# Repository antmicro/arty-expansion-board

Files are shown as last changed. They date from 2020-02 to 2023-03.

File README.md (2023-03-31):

# Antmicro Arty A7 expansion board

Copyright (c) 2019-2023 [Antmicro](https://www.antmicro.com)



Arty A7 Expansion Board

## Overview

This project contains open hardware design files for expansion board compatible with Digilent [Arty A7 development platform](https://store.digilentinc.com/arty-a7-artix-7-fpga-development-board-for-makers-and-hobbyists/).
The expansion board utilizes a set of PMOD connectors on Arty board to provide additional IO interfaces.

## Project structure

The main directory contains the KiCAD design files, LICENSE and README.
The remaining files are stored in the following directories:

* ``3d-model`` -  contains mechanical model of the board
* ``lib`` - contains the component libraries
* ``doc`` - contains selected files for device fabrication (schematic in PDF, BoM)
* ``img`` - contains graphics for this README

## Key features

* HDMI connector
* microSD card connector
* USB 2.0 host controller implemented with Maxim [MAX3421EEHJ](https://datasheets.maximintegrated.com/en/ds/MAX3421E.pdf)
* Analog audio output implemented with Cirrus Logic [CS4344](https://www.cirrus.com/products/cs4344-45-48) D/A converter
* Analog (line) audio input implemented with Cirrus Logic [CS5343](https://www.cirrus.com/products/cs5343-44) A/D converter
* GPIO expander with LED indicators

## License

This project is licensed under the [Apache-2.0 ](LICENSE) license.

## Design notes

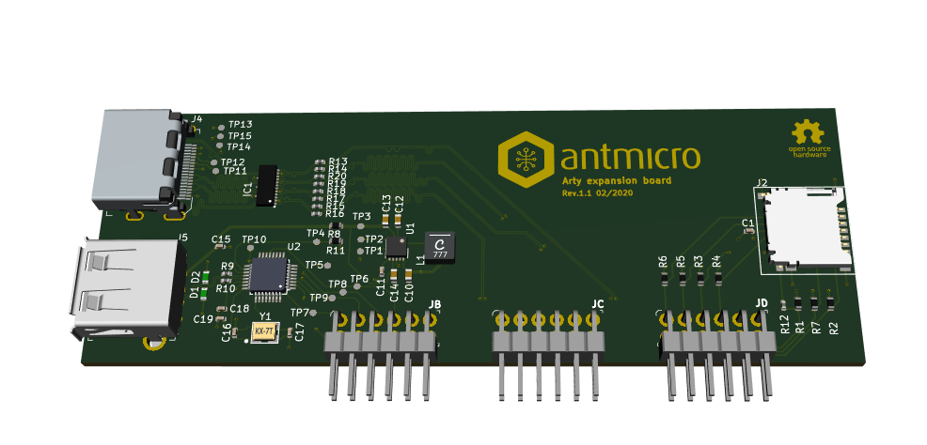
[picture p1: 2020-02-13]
img/expansion-board.png

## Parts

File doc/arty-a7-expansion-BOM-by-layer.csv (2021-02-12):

Reference | Quantity | Value | Footprint | Manufacturer | MPN | Layer
C1 C15 C18 C19 C31 | 5 | C_100n_0402_6V3 | 0402-cap | Walsin | 0402X104K6R3CT | Top
C10 C12 C13 C14 | 4 | C_22u_0603 | 0603-cap | MURATA | GRM188R60J226MEA0D | Top
C11 | 1 | C_10n_0402 | 0402-cap | AVX | 04025G103ZAT2A | Top
C16 C17 | 2 | C_22p_0402 | 0402-cap | YAGEO | CC0402JRNPO9BN220 | Top
C2 C3 C6 C7 C8 C21 C22 | 7 | C_100n_0402_16V | 0402-cap | MULTICOMP | MC0402B104K160CT | Top
C24 C27 C28 | 3 | C_1u_0402 | 0402-cap | TDK | C1005X6S1A105K050BC | Top
C25 C26 | 2 | C_3u3_0603 | 0603-cap | KEMET | C0603C335M9PACTU | Top
C29 C30 | 2 | C_2n7_0603 | 0603-cap | KEMET | C0603C272K5RACTU | Top
C32 C33 | 2 | C_180p_0402 | 0402-cap | AVX | 04025A181JAT2A | Top
C4 C5 | 2 | C_4u7_0402 | 0402-cap | MURATA | GRM155R61A475MEAAD | Top
C9 C20 C23 | 3 | C_10u_0402 | 0402-cap | MURATA | GRM155R60J106ME44D | Top
D1 D2 | 2 | PGB1010603MR | PGB1010603MR | Littelfuse Inc. | PGB1010603MR | Top
D3 D4 D5 D6 D7 D8 | 6 | LG_L29K-G2J1-24-Z | LED_0603 | OSRAM Opto Semiconductors Inc. | LG L29K-G2J1-24-Z | Top
FB1 FB2 | 2 | BLM15AG601SN1D | 0402-res | Murata | BLM15AG601SN1D | Top
IC1 | 1 | TPD8S009DSMR | R-PDSO-N15 | Texas Instruments | TPD8S009DSMR | Top
IC2 | 1 | PCA9500PW | TSSOP-16 | NXP | PCA9500PW | Top
J1 | 1 | SJ-43516-SMT-GR | CUI_SJ-43516-SMT-GR | CUI Inc | SJ-43516-SMT-GR | Top
J2 | 1 | DM3AT-SF-PEJM5 | MicroSD_DM3AT-SF-PEJM5 | HIROSE | DM3AT-SF-PEJM5 | Top
J3 | 1 | SJ-43516-SMT-BE | CUI_SJ-43516-SMT-BE | CUI Inc | SJ-43516-SMT-BE | Top
J4 | 1 | 685119134923 | HDMI_A_Female_685119134923 | Amphenol | 685119134923 | Top
J5 | 1 | UE27AC54100 | USB_A_Female_UE27AC54100 | Amphenol ICC (Commercial Products) | UE27AC54100 | Top
JA1 JB1 JC1 JD1 | 4 | 10883121 | PinHeader_6x2_P2.54mm_Horizontal_Mirrored | Molex | 10883121 | Top
L1 | 1 | XFL4020-102MEC | XFL4020-102MEB | Coilcraft | XFL4020-102MEC | Top
Q1 | 1 | BSS138APW | SC70-3 | ON Semiconductor | BSS138PW | Top
R1 R2 R3 R4 R5 R6 R7 | 7 | R_20k_0402 | 0402-res | VISHAY | CRCW040220K0FKED | Top
R11 R24 R28 R30 | 4 | R_10k_0402 | 0402-res | VISHAY | CRCW040210K0FKEDHP | Top
R12 | 1 | R_220R_0402 | 0402-res | Panasonic | ERJ2GEJ221X | Top
R22 R23 | 2 | R_1R_0402 | 0402-res | YAGEO | RC0402FR-071RL | Top
R29 R31 R34 R35 | 4 | R_5k1_0603 | 0603-res | Vishay | CRCW06035K10FKEA | Top
R32 R33 | 2 | R_470R_0402 | 0402-res | VISHAY | CRCW0402470RFKED | Top
R36 R37 | 2 | R_2k_0402 | 0402-res | VISHAY | CRCW04022K00FKED | Top
R38 | 1 | R_100k_0402 | 0402-res | VISHAY | CRCW0402100KFKEDHP | Top
R40 R41 R42 R43 | 4 | R_100R_0402 | 0402-res | BOURNS | CR0402-FX-1000GLF | Top
R44 R46 | 2 | R_330R_0402 | 0402-res | MULTICOMP | MCMR04X3300FTL | Top
R45 | 1 | R_10k_0402 | 0402-res | VISHAY | CRCW040210K0FKEDHP | Top
R8 R13 R14 R15 R16 R17 R18 R19 R20 R21 R25 R26 R27 R39 | 14 | R_0R_0402 | 0402-res | PANASONIC | ERJ2GE0R00X | Top
R9 R10 | 2 | R_22R_0402 | 0402-res | VISHAY | CRCW040222R0FKED | Top
U1 | 1 | TPS61232DRCT | VSON-10-1EP_3x3mm | Texas Instruments | TPS61232DRCT | Top
U2 | 1 | MAX3421EEHJ | TQFP-32_5x5mm | Maxim integrated | MAX3421EEHJ | Top
U3 | 1 | CS4344-CZZ | 10TSSOP | Cirrus Logic | CS4344-CZZ | Top
U4 | 1 | CS5343-CZZ | 10TSSOP | Cirrus Logic | CS5343-CZZ | Top
U5 | 1 | NC7SZ126P5X | SC-70-5 | ON Semiconductor | NC7SZ126P5X | Top
Y1 | 1 | ABM8G-12.000MHZ-18-D2Y-T | KX-7 | Abracon | ABM8G-12.000MHZ-18-D2Y-T | Top
N1 | 1 | antmicro_logo | antmicro-logo_scaled_30mm |  |  | Virtual
N2 | 1 | oshw_logo | oshw-logo |  |  | Virtual
TP1 TP2 TP3 TP5 TP6 TP7 TP8 TP9 TP10 TP11 TP12 TP13 TP14 TP15 | 14 | TP_SMD1MM | Testpoint_smd_1mm |  |  | Virtual
TP4 | 1 | TP_SMD1MM- | Testpoint_smd_1mm |  |  | Virtual

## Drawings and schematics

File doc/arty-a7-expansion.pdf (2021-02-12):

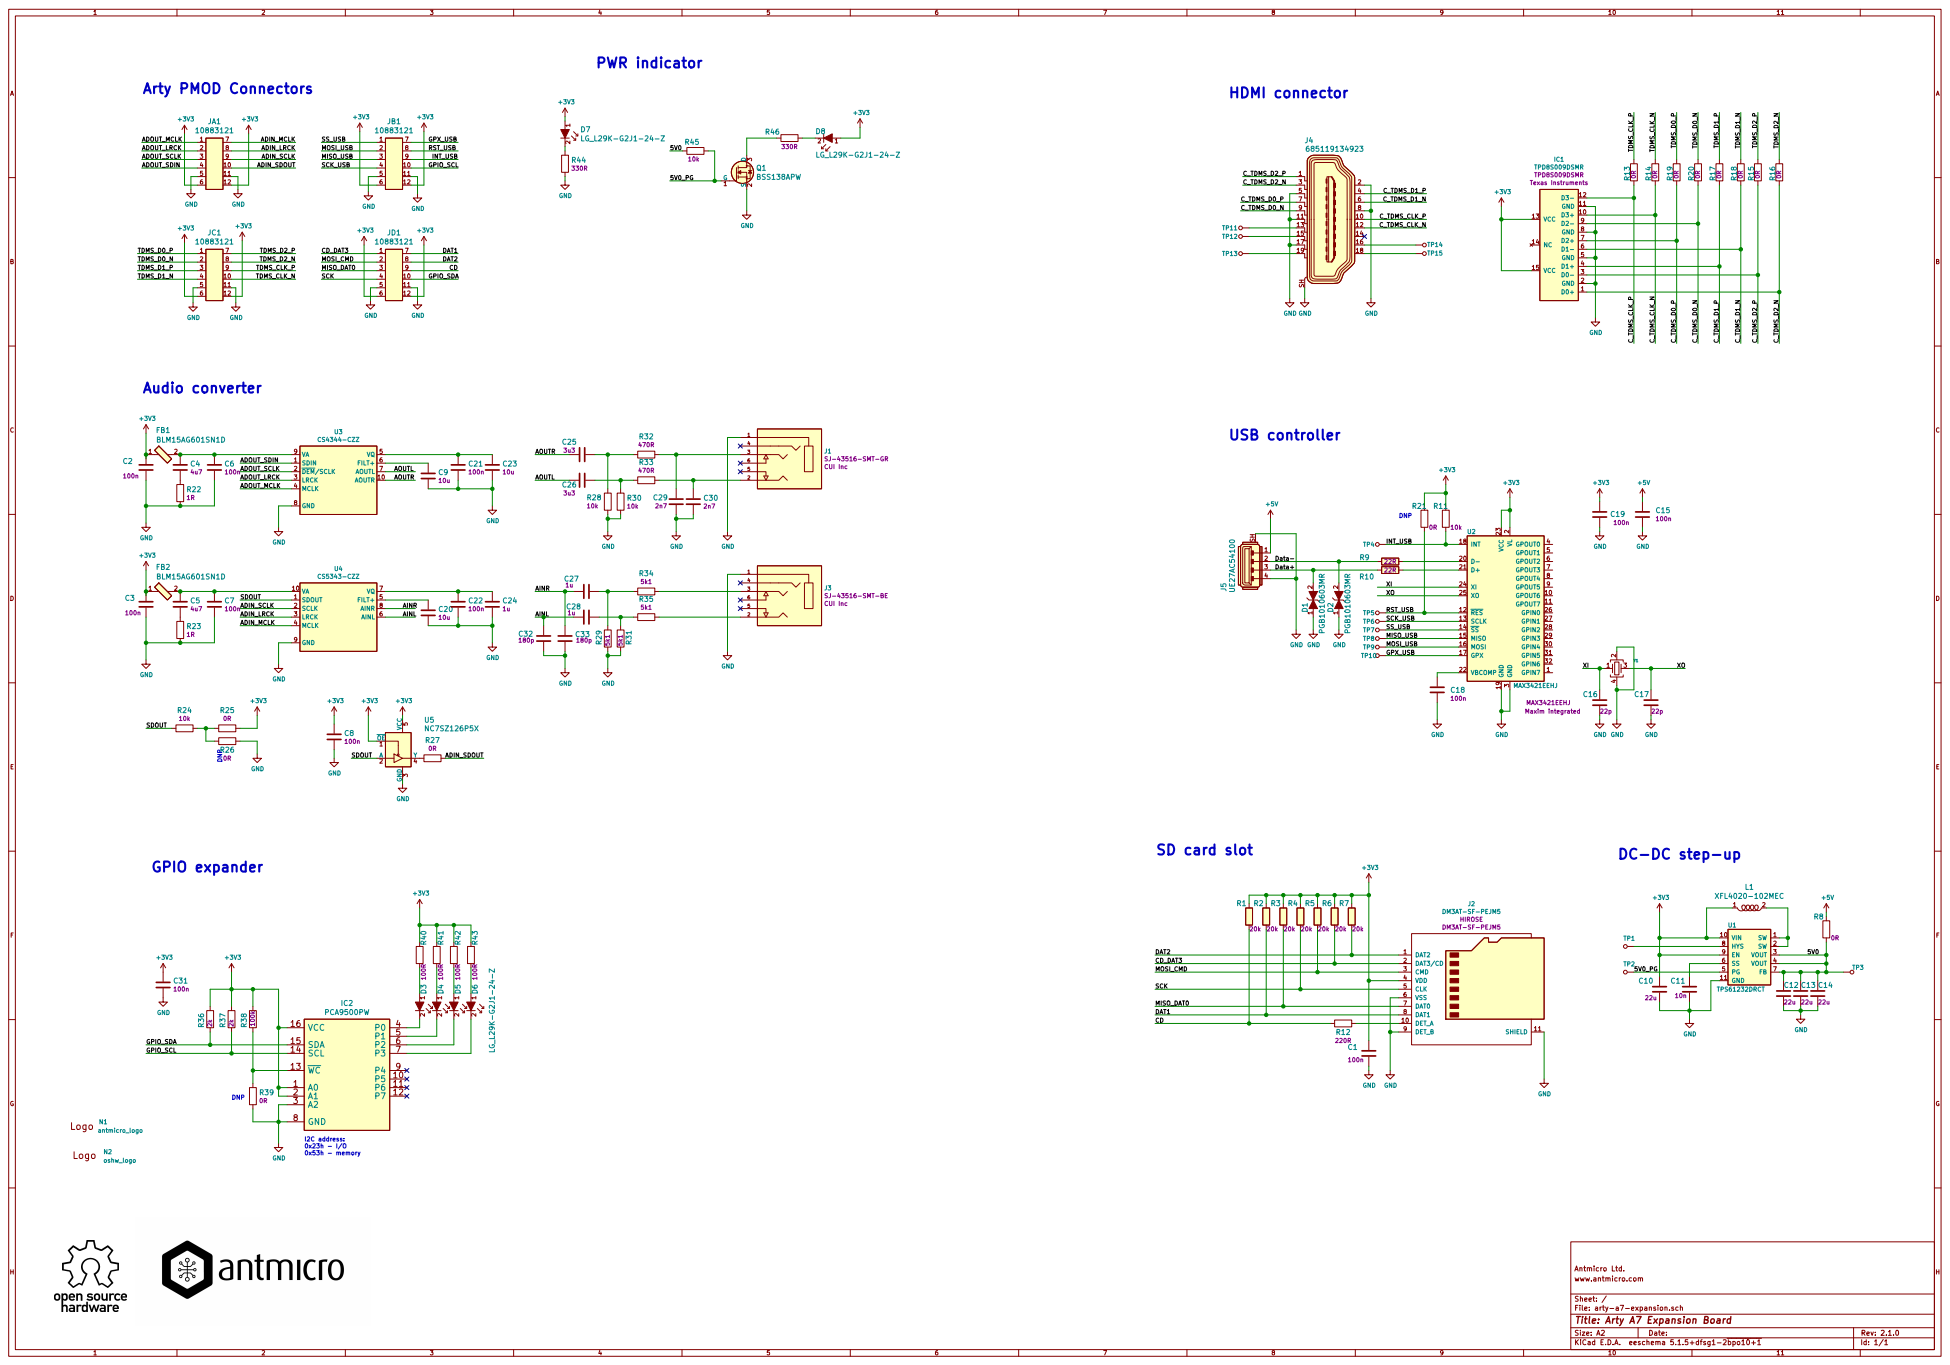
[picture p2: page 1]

4 | 10
5 | 11

Antmicro Ltd.
File: arty-a7-expansion.sch Sheet: / www.antmicro.com

Id: 1/1 Title: Arty A7 Expansion Board

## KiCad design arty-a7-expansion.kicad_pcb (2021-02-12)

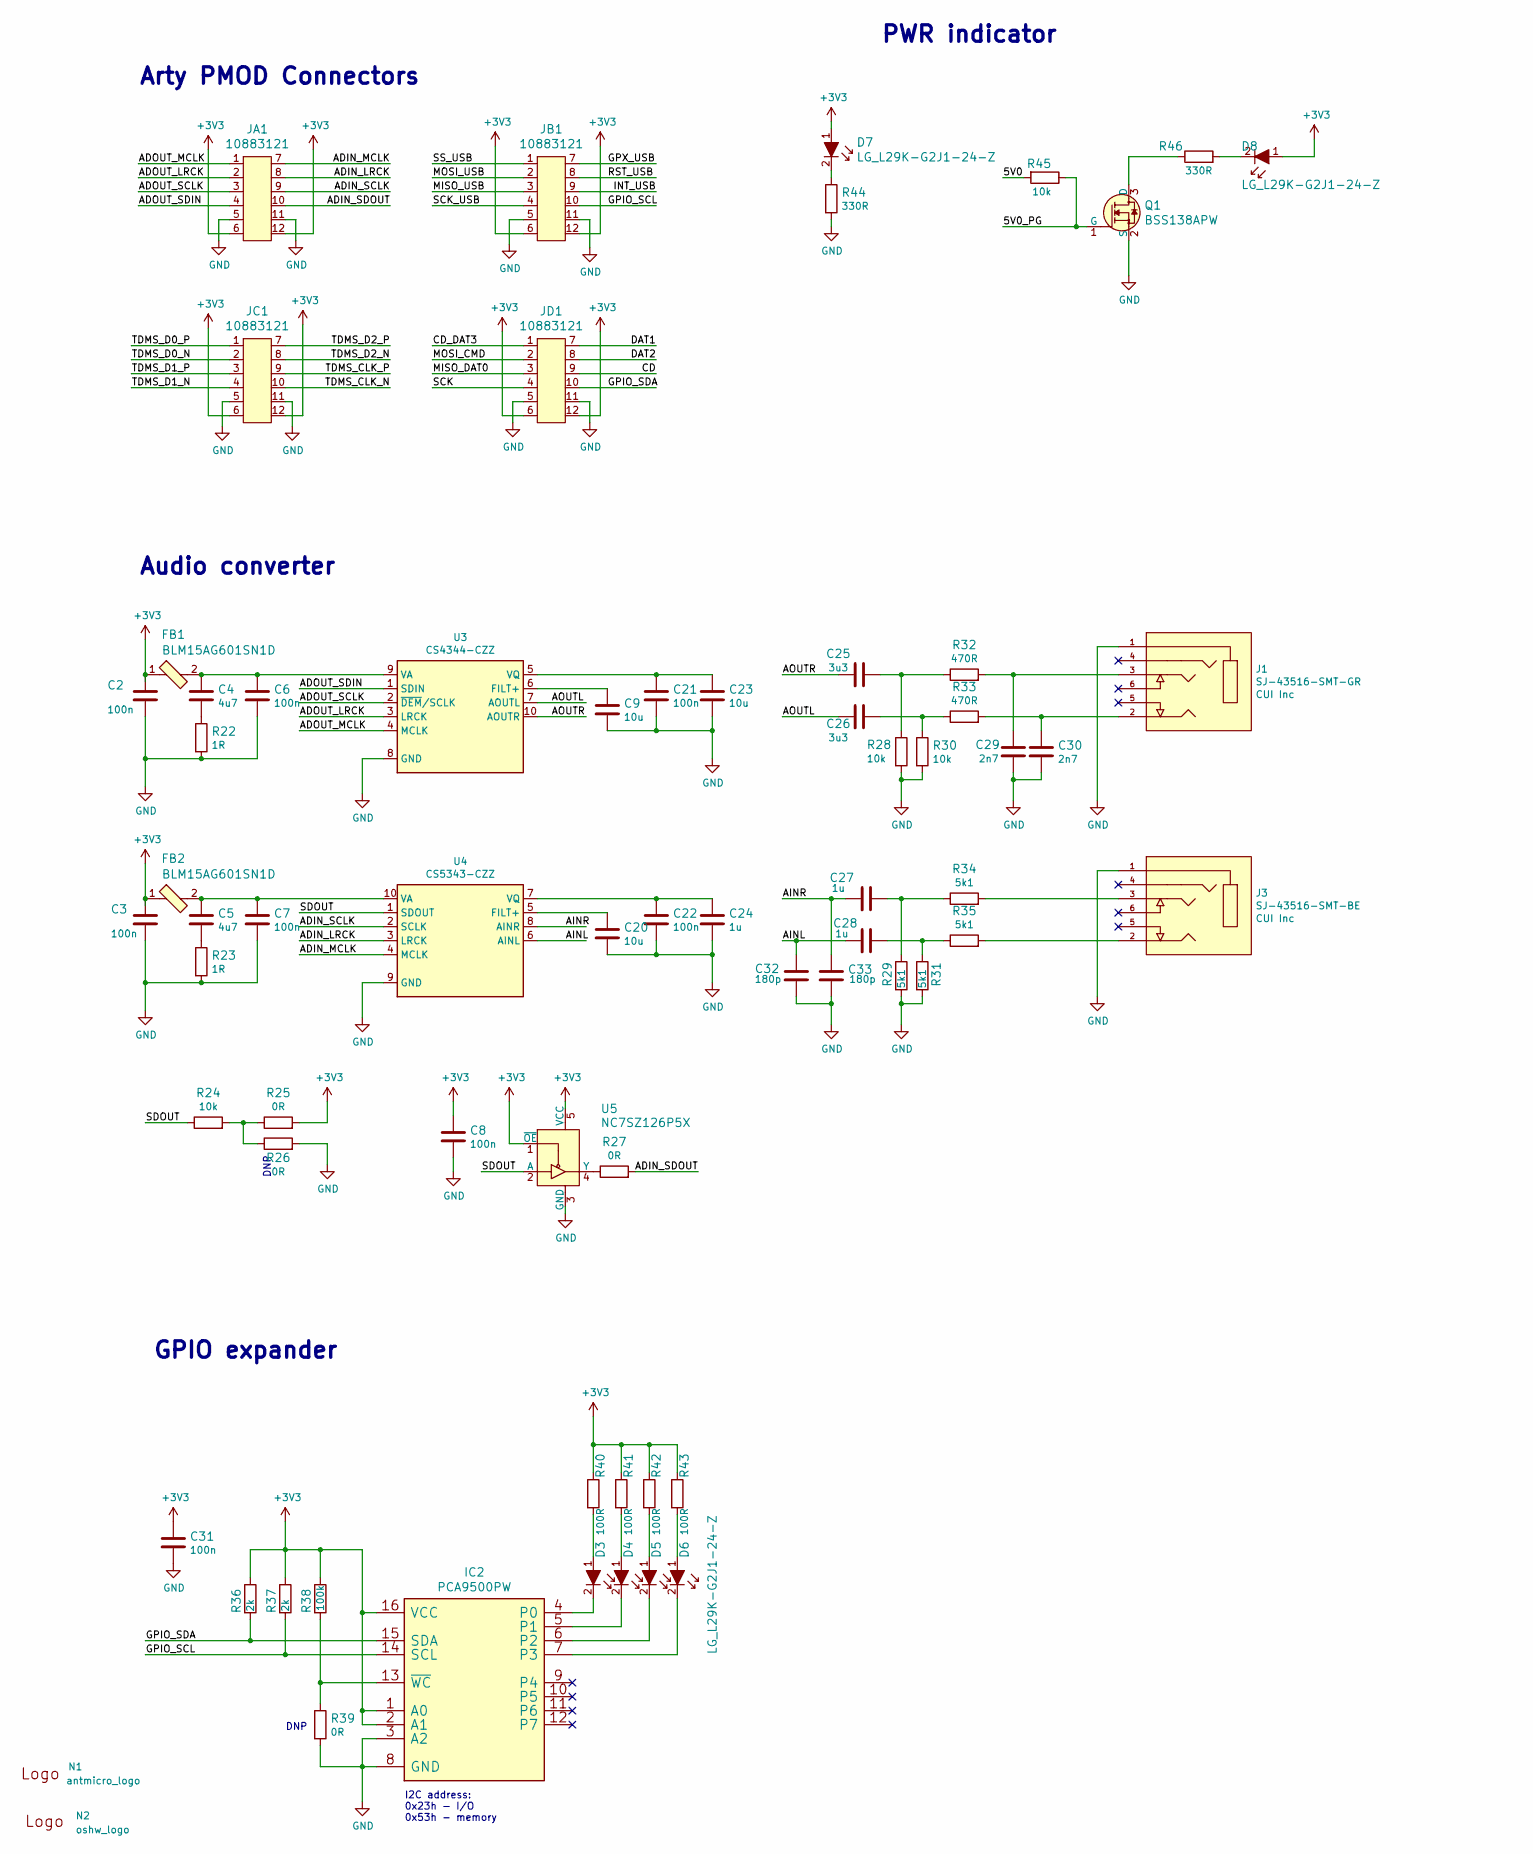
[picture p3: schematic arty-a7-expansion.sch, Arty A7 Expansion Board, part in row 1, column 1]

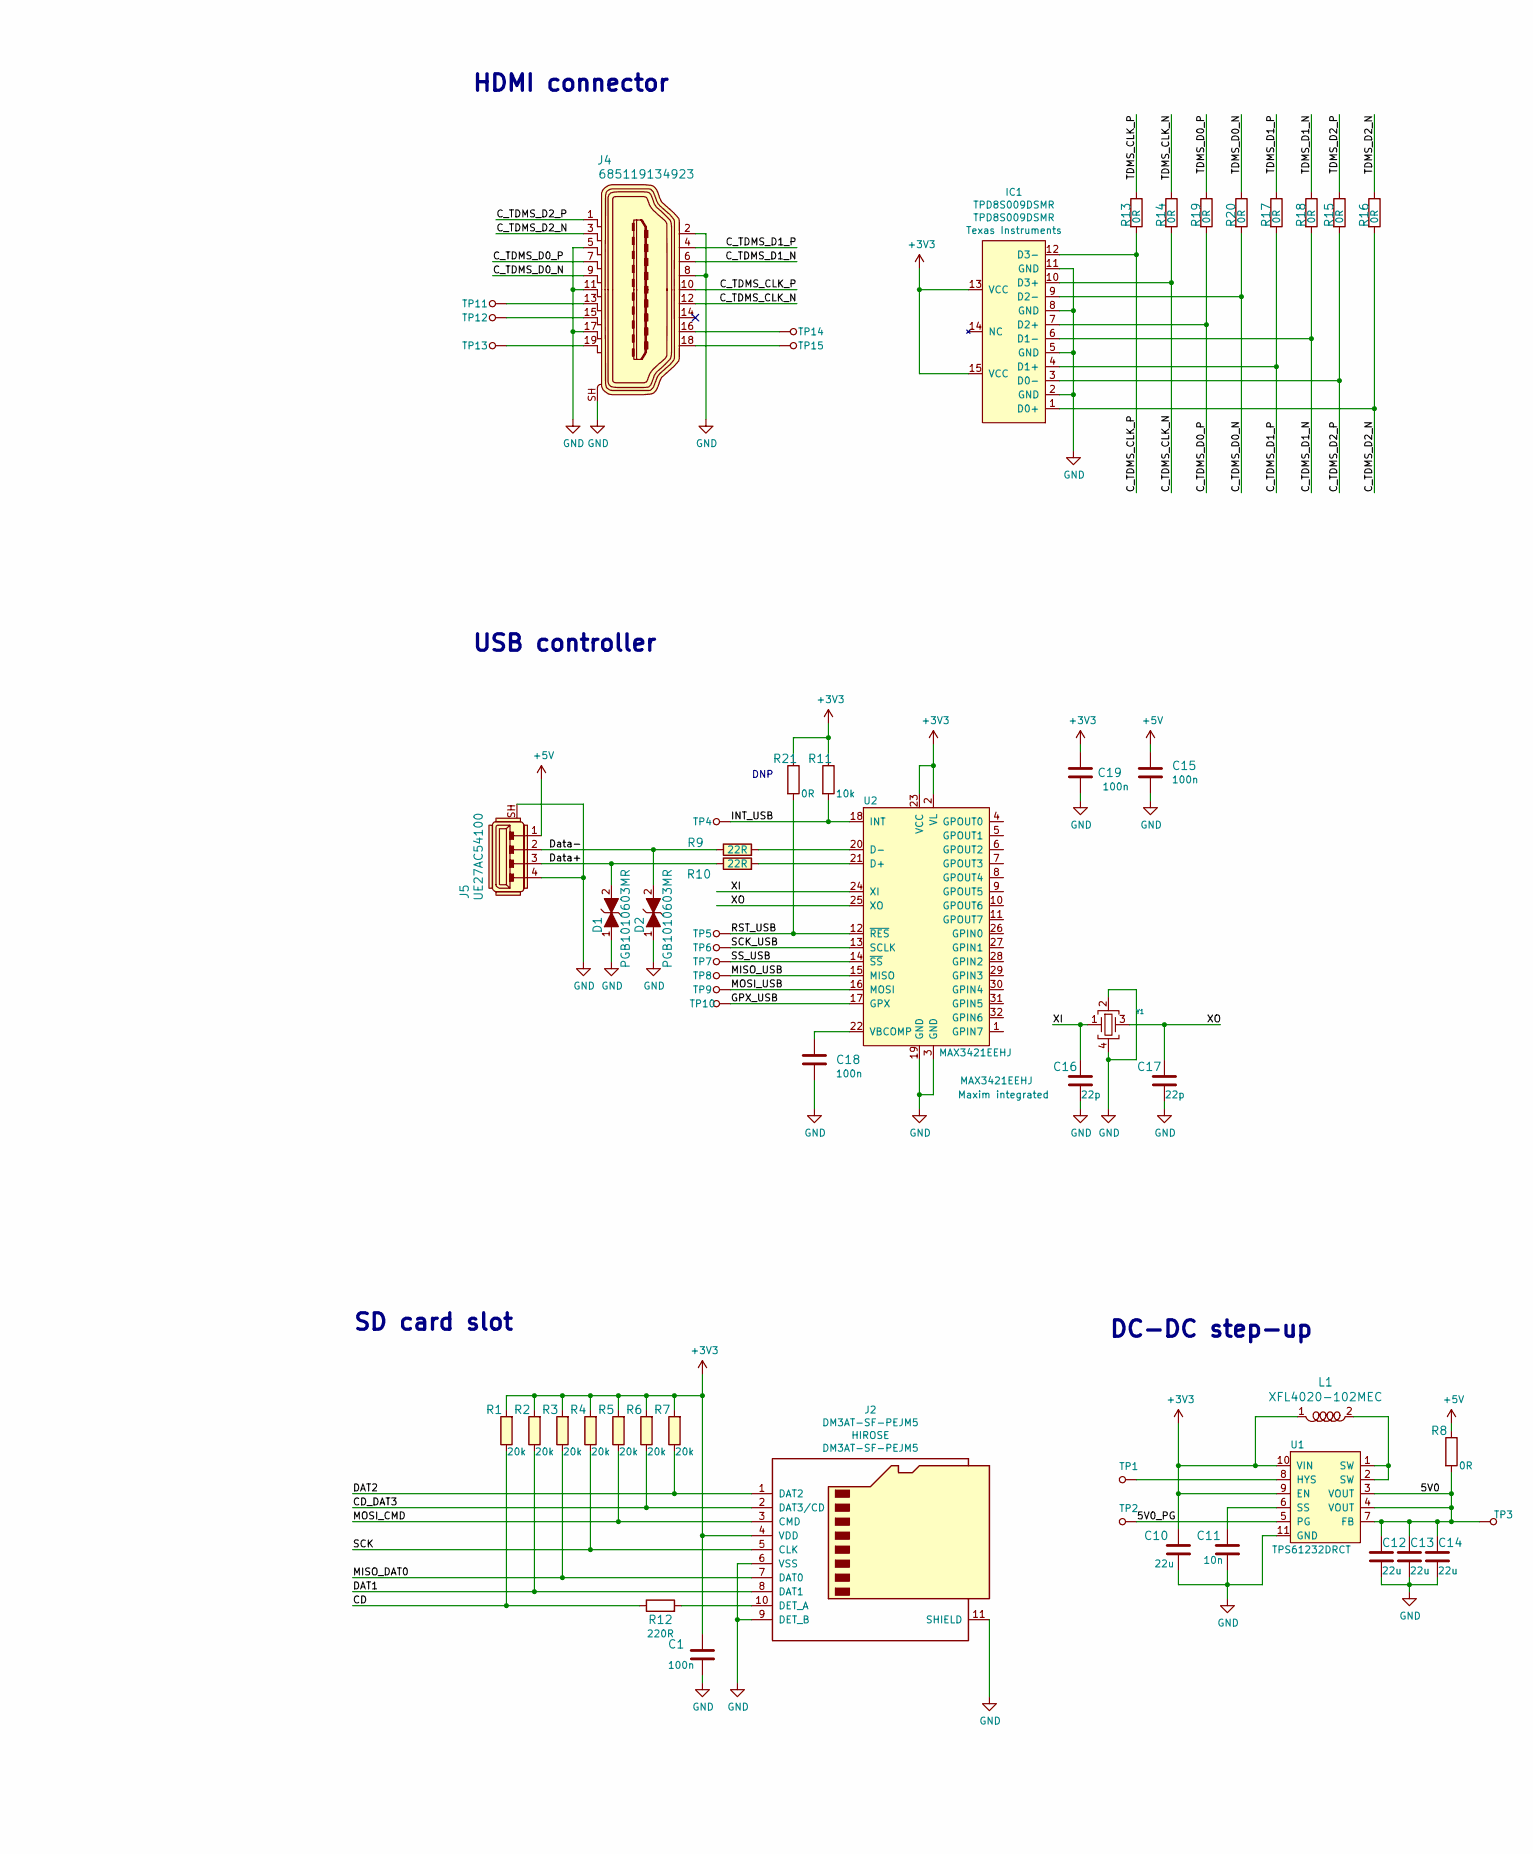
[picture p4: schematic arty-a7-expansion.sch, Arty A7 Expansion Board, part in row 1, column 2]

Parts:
C1, C15, C18, C19, C31: C_100n_0402_6V3; 0402-cap; MPN 0402X104K6R3CT
C2, C3, C6, C7, C8, C21, C22: C_100n_0402_16V; 0402-cap; MPN MC0402B104K160CT
C4, C5: C_4u7_0402; 0402-cap; MPN GRM155R61A475MEAAD
C9, C20, C23: C_10u_0402; 0402-cap; MPN C1005X5R0J106M050BC
C10, C12, C13, C14: C_22u_0603; 0603-cap; MPN GRM188R60J226MEA0D
C11: C_10n_0402; 0402-cap; MPN 04025G103ZAT2A
C16, C17: C_22p_0402; 0402-cap; MPN CC0402JRNPO9BN220
C24, C27, C28: C_1u_0402; 0402-cap; MPN C1005X6S1A105K050BC
C25, C26: C_3u3_0603; 0603-cap; MPN C0603C335M9PACTU
C29, C30: C_2n7_0603; 0603-cap; MPN C0603C272K5RACTU
C32, C33: C_180p_0402; 0402-cap; MPN 04025A181JAT2A
D1, D2: PGB1010603MR; MPN PGB1010603MR
D3, D4, D5, D6, D7, D8: LG_L29K-G2J1-24-Z; LED_0603; MPN LG L29K-G2J1-24-Z
FB1, FB2: BLM15AG601SN1D; 0402-res; MPN BLM15AG601SN1D
IC1: TPD8S009DSMR; R-PDSO-N15; MPN TPD8S009DSMR
IC2: PCA9500PW; TSSOP-16; MPN PCA9500PW
J1: SJ-43516-SMT-GR; CUI_SJ-43516-SMT-GR; MPN SJ-43516-SMT-GR
J2: DM3AT-SF-PEJM5; MicroSD_DM3AT-SF-PEJM5; MPN DM3AT-SF-PEJM5
J3: SJ-43516-SMT-BE; CUI_SJ-43516-SMT-BE; MPN SJ-43516-SMT-BE
J4: 685119134923; HDMI_A_Female_685119134923; MPN 685119134923
J5: UE27AC54100; USB_A_Female_UE27AC54100; MPN UE27AC54100
JA1: 10883121; PinHeader_6x2_P2.54mm_Horizontal_Mirrored; MPN 10883121
JB1: 10883121; PinHeader_6x2_P2.54mm_Horizontal_Mirrored; MPN 10883121
JC1: 10883121; PinHeader_6x2_P2.54mm_Horizontal_Mirrored; MPN 10883121
JD1: 10883121; PinHeader_6x2_P2.54mm_Horizontal_Mirrored; MPN 10883121
L1: XFL4020-102MEC; XFL4020-102MEB; MPN XFL4020-102MEC
N1: antmicro_logo; antmicro-logo_scaled_30mm
N2: oshw_logo; oshw-logo
Q1: BSS138APW; SC70-3; MPN BSS138PW
R1, R2, R3, R4, R5, R6, R7: R_20k_0402; 0402-res; MPN CRCW040220K0FKED
R8, R13, R14, R15, R16, R17, R18, R19, R20, R21, R25, R26, R27, R39: R_0R_0402; 0402-res; MPN ERJ2GE0R00X
R9, R10: R_22R_0402; 0402-res; MPN CRCW040222R0FKED
R11, R24, R28, R30, R45: R_10k_0402; 0402-res; MPN CRCW040210K0FKEDHP
R12: R_220R_0402; 0402-res; MPN ERJ2GEJ221X
R22, R23: R_1R_0402; 0402-res; MPN RC0402FR-071RL
R29, R31, R34, R35: R_5k1_0603; 0603-res; MPN CRCW06035K10FKEA
R32, R33: R_470R_0402; 0402-res; MPN CRCW0402470RFKED.
R36, R37: R_2k_0402; 0402-res; MPN CRCW04022K00FKED
R38: R_100k_0402; 0402-res; MPN CRCW0402100KFKEDHP
R40, R41, R42, R43: R_100R_0402; 0402-res; MPN CR0402-FX-1000GLF
R44, R46: R_330R_0402; 0402-res; MPN MCMR04X3300FTL
TP1, TP2, TP3, TP4, TP5, TP6, TP7, TP8, TP9, TP10, TP11, TP12, TP13, TP14, TP15: TP_SMD1MM; Testpoint_smd_1mm
U1: TPS61232DRCT; VSON-10-1EP_3x3mm; MPN TPS61232DRCT
U2: MAX3421EEHJ; TQFP-32_5x5mm; MPN MAX3421EEHJ
U3: CS4344-CZZ; 10TSSOP; MPN CS4344-CZZ
U4: CS5343-CZZ; 10TSSOP; MPN CS5343-CZZ
U5: NC7SZ126P5X; SC-70-5; MPN NC7SZ126P5X
Y1: ABM8G-12.000MHZ-18-D2Y-T; KX-7; MPN ABM8G-12.000MHZ-18-D2Y-T

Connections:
+3V3: C1.1, C2.1, C3.1, C8.1, C10.1, C19.2, C31.2, D7.1, D8.1, FB1.1, FB2.1, IC1.13 (VCC), IC1.15 (VCC), IC2.1 (A0), IC2.2 (A1), IC2.16 (VCC), J2.4 (VDD), JA1.6, JA1.12, JB1.6, JB1.12, JC1.6, JC1.12, JD1.6, JD1.12, L1.1, R1.2, R2.2, R3.2, R4.2, R5.2, R6.2, R7.2, R11.1, R21.1, R25.2, R36.1, R37.1, R38.1, R40.1, R41.1, R42.1, R43.1, U1.9 (EN), U1.10 (VIN), U2.2 (VL), U2.23 (VCC), U5.1 (~OE), U5.5 (VCC)
+5V: C15.1, J5.1, R8.1
/5V0: C12.1, C13.1, C14.1, R8.2, R45.2, TP3.1, U1.3 (VOUT), U1.4 (VOUT), U1.7 (FB)
/5V0_PG: Q1.1 (G), R45.1, TP2.1, U1.5 (PG)
/ADIN_LRCK: JA1.8, U4.3 (LRCK)
/ADIN_MCLK: JA1.7, U4.4 (MCLK)
/ADIN_SCLK: JA1.9, U4.2 (SCLK)
/ADIN_SDOUT: JA1.10, R27.2
/ADOUT_LRCK: JA1.2, U3.3 (LRCK)
/ADOUT_MCLK: JA1.1, U3.4 (MCLK)
/ADOUT_SCLK: JA1.3, U3.2 (~DEM~/SCLK)
/ADOUT_SDIN: JA1.4, U3.1 (SDIN)
/AINL: C28.2, C32.2, U4.6 (AINL)
/AINR: C27.2, C33.2, U4.8 (AINR)
/AOUTL: C26.2, U3.7 (AOUTL)
/AOUTR: C25.2, U3.10 (AOUTR)
/CD: JD1.9, R1.1, R12.1
/CD_DAT3: J2.2 (DAT3/CD), JD1.1, R6.1
/C_TDMS_CLK_N: IC1.10 (D3+), J4.12, R14.2
/C_TDMS_CLK_P: IC1.12 (D3-), J4.10, R13.2
/C_TDMS_D0_N: IC1.9 (D2-), J4.9, R20.2
/C_TDMS_D0_P: IC1.7 (D2+), J4.7, R19.2
/C_TDMS_D1_N: IC1.6 (D1-), J4.6, R18.2
/C_TDMS_D1_P: IC1.4 (D1+), J4.4, R17.2
/C_TDMS_D2_N: IC1.1 (D0+), J4.3, R16.2
/C_TDMS_D2_P: IC1.3 (D0-), J4.1, R15.2
/DAT1: J2.8 (DAT1), JD1.7, R2.1
/DAT2: J2.1 (DAT2), JD1.8, R7.1
/Data+: D1.2, J5.3, R10.1
/Data-: D2.2, J5.2, R9.1
/GPIO_SCL: IC2.14 (SCL), JB1.10, R37.2
/GPIO_SDA: IC2.15 (SDA), JD1.10, R36.2
/GPX_USB: JB1.7, TP10.1, U2.17 (GPX)
/INT_USB: JB1.9, R11.2, TP4.1, U2.18 (INT)
/MISO_DAT0: J2.7 (DAT0), JD1.3, R3.1
/MISO_USB: JB1.3, TP8.1, U2.15 (MISO)
/MOSI_CMD: J2.3 (CMD), JD1.2, R5.1
/MOSI_USB: JB1.2, TP9.1, U2.16 (MOSI)
/RST_USB: JB1.8, R21.2, TP5.1, U2.12 (~RES)
/SCK: J2.5 (CLK), JD1.4, R4.1
/SCK_USB: JB1.4, TP6.1, U2.13 (SCLK)
/SDOUT: R24.1, U4.1 (SDOUT), U5.2 (A)
/SS_USB: JB1.1, TP7.1, U2.14 (~SS)
/TDMS_CLK_N: JC1.10, R14.1
/TDMS_CLK_P: JC1.9, R13.1
/TDMS_D0_N: JC1.2, R20.1
/TDMS_D0_P: JC1.1, R19.1
/TDMS_D1_N: JC1.4, R18.1
/TDMS_D1_P: JC1.3, R17.1
/TDMS_D2_N: JC1.8, R16.1
/TDMS_D2_P: JC1.7, R15.1
/XI: C16.1, U2.24 (XI), Y1.1
/XO: C17.1, U2.25 (XO), Y1.3
GND: C1.2, C2.2, C3.2, C6.2, C7.2, C8.2, C9.2, C10.2, C11.2, C12.2, C13.2, C14.2, C15.2, C16.2, C17.2, C18.2, C19.1, C20.2, C21.2, C22.2, C23.2, C24.2, C29.2, C30.2, C31.1, C32.1, C33.1, D1.1, D2.1, IC1.2 (GND), IC1.5 (GND), IC1.8 (GND), IC1.11 (GND), IC2.3 (A2), IC2.8 (GND), J1.1, J2.6 (VSS), J2.9 (DET_B), J2.11 (SHIELD), J3.1, J4.2, J4.5, J4.8, J4.11, J4.17, J4.SH, J5.4, J5.SH, JA1.5, JA1.11, JB1.5, JB1.11, JC1.5, JC1.11, JD1.5, JD1.11, Q1.2 (S), R22.2, R23.2, R26.2, R28.2, R29.2, R30.2, R31.2, R39.2, R44.2, U1.11 (GND), U2.3 (GND), U2.19 (GND), U3.8 (GND), U4.9 (GND), U5.3 (GND), Y1.2, Y1.4
unnamed: C4.1, C6.1, FB1.2, U3.9 (VA)
unnamed: C4.2, R22.1
unnamed: C5.1, C7.1, FB2.2, U4.10 (VA)
unnamed: C5.2, R23.1
unnamed: C9.1, U3.6 (FILT+)
unnamed: C11.1, U1.6 (SS)
unnamed: C18.1, U2.22 (VBCOMP)
unnamed: C20.1, U4.5 (FILT+)
unnamed: C21.1, C23.1, U3.5 (VQ)
unnamed: C22.1, C24.1, U4.7 (VQ)
unnamed: C25.1, R28.1, R32.1
unnamed: C26.1, R30.1, R33.1
unnamed: C27.1, R29.1, R34.1
unnamed: C28.1, R31.1, R35.1
unnamed: C29.1, J1.3, R32.2
unnamed: C30.1, J1.2, R33.2
unnamed: D3.1, R40.2
unnamed: D3.2, IC2.4 (P0)
unnamed: D4.1, R41.2
unnamed: D4.2, IC2.5 (P1)
unnamed: D5.1, R42.2
unnamed: D5.2, IC2.6 (P2)
unnamed: D6.1, R43.2
unnamed: D6.2, IC2.7 (P3)
unnamed: D7.2, R44.1
unnamed: D8.2, R46.2
unnamed: IC2.13 (~WC), R38.2, R39.1
unnamed: J2.10 (DET_A), R12.2
unnamed: J3.2, R35.2
unnamed: J3.3, R34.2
unnamed: J4.13, TP11.1
unnamed: J4.15, TP12.1
unnamed: J4.16, TP14.1
unnamed: J4.18, TP15.1
unnamed: J4.19, TP13.1
unnamed: L1.2, U1.1 (SW), U1.2 (SW)
unnamed: Q1.3 (D), R46.1
unnamed: R9.2, U2.20 (D-)
unnamed: R10.2, U2.21 (D+)
unnamed: R24.2, R25.1, R26.1
unnamed: R27.1, U5.4 (Y)
unnamed: TP1.1, U1.8 (HYS)

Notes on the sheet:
Arty PMOD Connectors
HDMI connector
SD card slot
DC-DC step-up
USB controller
DNP
Audio converter
GPIO expander
I2C address: 0x23h - I/O 0x53h - memory
PWR indicator

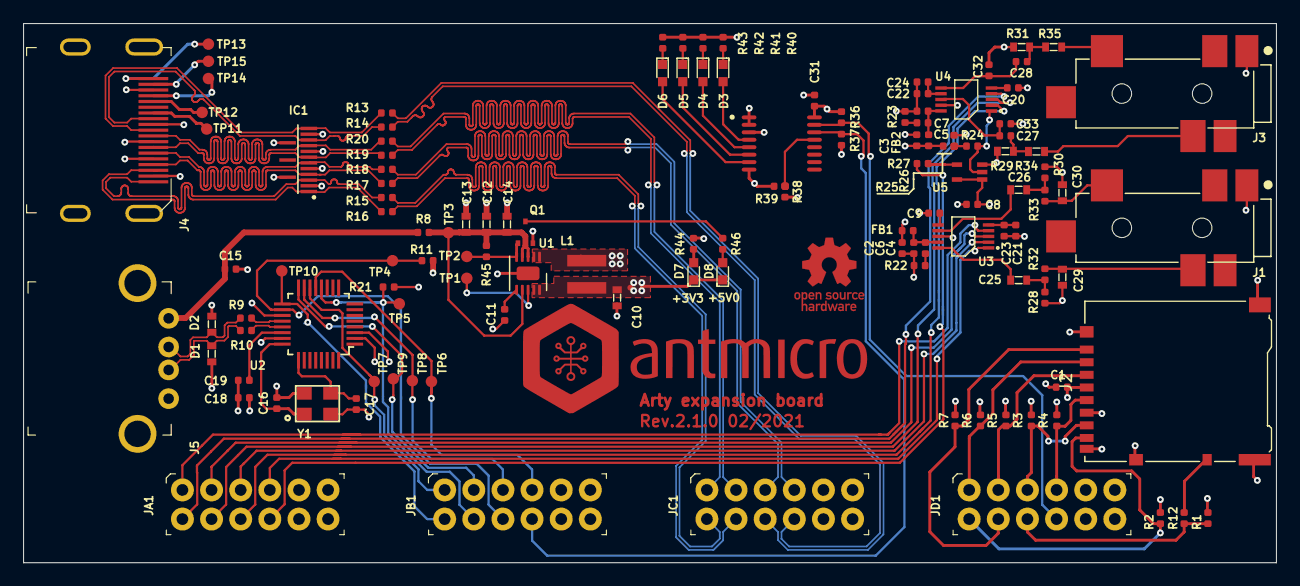
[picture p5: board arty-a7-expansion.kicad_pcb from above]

Board: 4 copper layers, 109.2 x 47.0 mm, 125 parts (0 on the bottom side), 96 nets.

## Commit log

2019-08-26 Add schematic file and component placement
    A schematic file and proposed arrangement of elements have been added.
    [HDMI_SD_expansion-B.Cu.gbr, HDMI_SD_expansion-B.Mask.gbr, HDMI_SD_expansion-B.Paste.gbr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]
2020-02-13 Replaced HDMI connector
    [HDMI_SD_expansion.sch]
2020-02-13 Added USB SPI Interface
    [HDMI_SD_expansion.kicad_pcb, HDMI_SD_expansion.sch]
2020-02-13 Schematic updates
    [HDMI_SD_expansion.kicad_pcb, HDMI_SD_expansion.sch]
2020-02-13 Added testpads
    [HDMI_SD_expansion.kicad_pcb, HDMI_SD_expansion.sch]
2020-02-13 Added 3D model of expansion board
2020-02-13 Optimized component placement
    [HDMI_SD_expansion.kicad_pcb, HDMI_SD_expansion.sch]
2020-02-13 Added logotype, rotated SD card
    [HDMI_SD_expansion.kicad_pcb]
2020-02-13 PCB routing
    [HDMI_SD_expansion-B.Cu.gbr, HDMI_SD_expansion-B.Mask.gbr, HDMI_SD_expansion-B.Paste.gbr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]
2020-02-13 Updated PMOD connectors on PCB
    [HDMI_SD_expansion-B.Cu.gbr, HDMI_SD_expansion-B.Mask.gbr, HDMI_SD_expansion-B.Paste.gbr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]
2020-02-13 Bug Fix
    [HDMI_SD_expansion-B.Cu.gbr, HDMI_SD_expansion-B.Mask.gbr, HDMI_SD_expansion-B.Paste.gbr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]
2020-02-13 Added more testpads
    [HDMI_SD_expansion-B.Cu.gbr, HDMI_SD_expansion-B.Mask.gbr, HDMI_SD_expansion-B.Paste.gbr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]
2020-02-13 Added PDF schematic
2020-02-13 Added TVS
    [HDMI_SD_expansion.sch, _saved_HDMI_SD_expansion.sch]
2020-02-13 Changed HDMI connector through hole
    [HDMI_SD_expansion.kicad_pcb, HDMI_SD_expansion.sch, _saved_HDMI_SD_expansion.sch]
2020-02-13 Prepared files for oshw release
    [HDMI_SD_expansion-B.Cu.gbr, HDMI_SD_expansion-B.Mask.gbr, HDMI_SD_expansion-B.Paste.gbr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]
2020-02-13 Introduced schematic sections
    [arty-a7-expansion-B_Cu.gbr, arty-a7-expansion-B_Mask.gbr, arty-a7-expansion-B_Paste.gbr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]
2020-02-13 Updated U1 MPN, updated layout around IC1
    [arty-a7-expansion-B_Cu.gbr, arty-a7-expansion-B_Mask.gbr, arty-a7-expansion-B_Paste.gbr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]
2020-02-14 Minor changes
    [arty-a7-expansion.kicad_pcb, arty-a7-expansion.sch]
2020-02-14 Added pullup resistor to USB_RESET, updated layout
    [arty-a7-expansion-B_Cu.gbr, arty-a7-expansion-B_Mask.gbr, arty-a7-expansion-B_Paste.gbr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]
2020-02-17 Added CSV files with BOM and Pick and Place
    [arty-a7-expansion-BOM-populated.csv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]
2020-02-17 Standardize components
    [arty-a7-expansion.kicad_pcb, arty-a7-expansion.sch]
2020-02-17 Update mpn
    [arty-a7-expansion.kicad_pcb, arty-a7-expansion.sch]
2020-02-17 Update library references
    [arty-a7-expansion.kicad_pcb]
2020-02-17 Update fabrication outputs
    [arty-a7-expansion-BOM-all.csv, arty-a7-expansion-BOM-by-layer.csv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]
2020-07-17 Add revision 2.0.1
    [arty-a7-expansion-BOM-all.csv, arty-a7-expansion-BOM-by-layer.csv, arty-a7-expansion-BOM-populated.csv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]
2021-02-12 Add PWR indicator
    [arty-a7-expansion.kicad_pcb, arty-a7-expansion.sch]
2021-02-12 Corrected silks
    [arty-a7-expansion.kicad_pcb]
2021-02-12 Replace micro SD card connector
    [arty-a7-expansion.kicad_pcb, arty-a7-expansion.sch]
2021-02-12 Add 5V0 led indicator
    [arty-a7-expansion.kicad_pcb, arty-a7-expansion.sch]
2021-02-12 Bump revision to 2.1.0
    [arty-a7-expansion.kicad_pcb, arty-a7-expansion.sch]
2021-02-12 PCB fabrication E1285910
2021-02-12 Update documentation
    [arty-a7-expansion-BOM-by-layer.csv, arty-a7-expansion-BOM-populated.csv]
